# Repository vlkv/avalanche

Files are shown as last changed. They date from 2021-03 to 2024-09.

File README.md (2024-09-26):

# The Avalanche keyboard

The Avalanche keyboard is an ergonomic split keyboard with 4x6 (or 3x6 if you **break off the 'digits' row**) column staggered keys,
5 thumb keys, **1 additional key for the pinky** (break off-able too) and 2 additional keys for the index finger (64 keys total).

Avalanche design was inspired by a number of great keyboards. You may read more about it
in my very first [reddit post](https://www.reddit.com/r/MechanicalKeyboards/comments/mkwddp/introducing_the_avalanche_yet_another_one_ergo/).

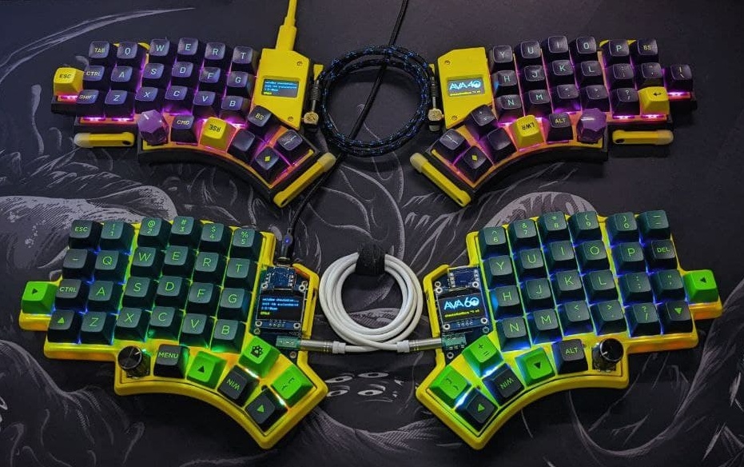
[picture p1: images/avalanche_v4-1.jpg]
The Avalanche keyboard v4

Avalanche v4 (Awesome 40% and 60% builds by [u/chewiedies](https://www.reddit.com/user/chewiedies))

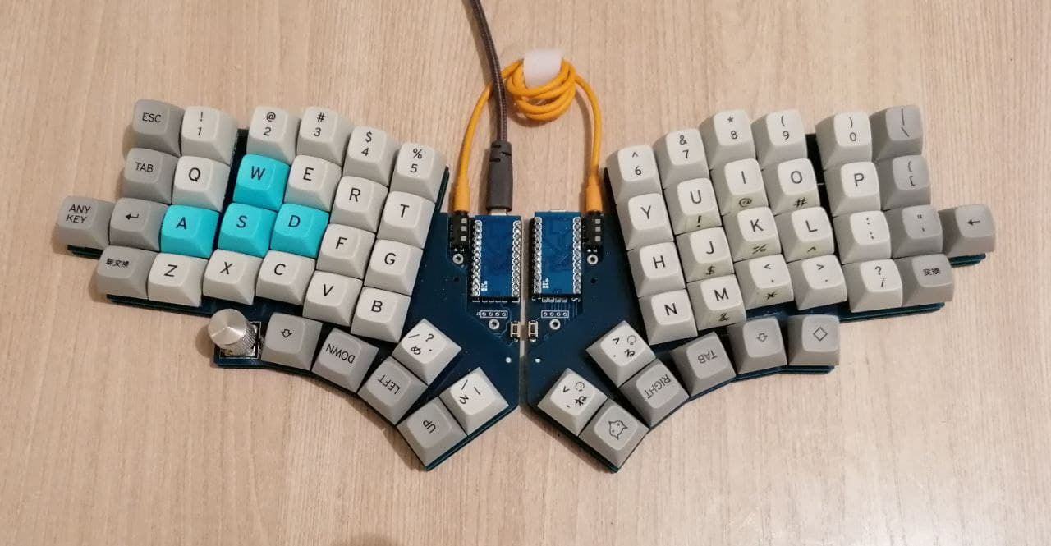
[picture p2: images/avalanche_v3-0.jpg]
The Avalanche keyboard v3

Avalanche v3

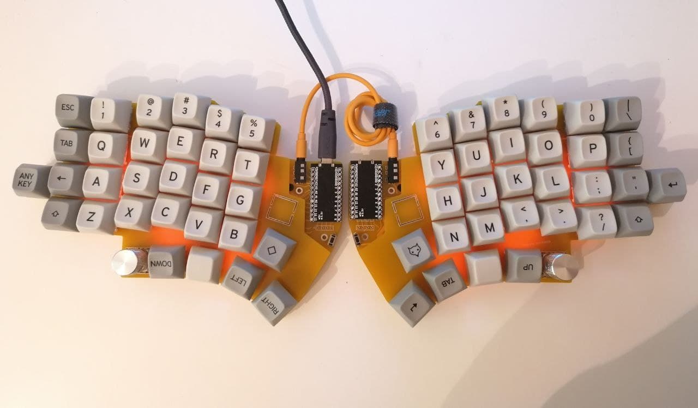
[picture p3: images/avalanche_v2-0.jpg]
The Avalanche keyboard v2

Avalanche v2

## Layout tester

Cut [left half](https://github.com/vlkv/avalanche/blob/master/layout_tester/pdf/Avalanche_v3_0_left_A4.pdf) and
[right half](https://github.com/vlkv/avalanche/blob/master/layout_tester/pdf/Avalanche_v3_0_right_A4.pdf)
from some piece of a cardboard, insert switches, put on the keycaps and try the layout.

## Gerber files

* [Version 4.2](https://github.com/vlkv/avalanche/tree/v4.2)
  * [PCB](https://github.com/vlkv/avalanche/blob/v4.2/pcb/Gerbers_pcb_v4_2.zip)
  * [Top plate](https://github.com/vlkv/avalanche/blob/v4.1/plate_top/Gerbers_plate_top_v4_1.zip)
  * [Bottom plate](https://github.com/vlkv/avalanche/blob/v4.1/plate_bottom/Gerbers_plate_bottom_v4_1.zip)
  * [60% 3D printed case](https://www.thingiverse.com/thing:5183389)
  * [40% 3D printed case](https://www.thingiverse.com/thing:5183613)
* [Version 3.1](https://github.com/vlkv/avalanche/tree/v3.1).
  * [PCB](https://github.com/vlkv/avalanche/blob/v3.1/pcb/Gerbers_pcb_v3_1.zip)
  * [Top plate](https://github.com/vlkv/avalanche/blob/v3.1/plate_top/Gerbers_plate_top_v3_0.zip)
  * [Bottom plate](https://github.com/vlkv/avalanche/blob/v3.1/plate_bottom/Gerbers_plate_bottom_v3_0.zip)
  * [Cover](https://github.com/vlkv/avalanche/blob/v3.1/cover/Gerbers_cover_v3_0.zip).
* [Version 3.0](https://github.com/vlkv/avalanche/tree/v3.0).
  * Known issues:
    * Still not fixed! https://github.com/vlkv/avalanche/issues/8
  * [PCB](https://github.com/vlkv/avalanche/blob/v3.0/pcb/Gerbers_pcb_v3_0.zip)
  * [Top plate](https://github.com/vlkv/avalanche/blob/v3.0/plate_top/Gerbers_plate_top_v3_0.zip)
  * [Bottom plate](https://github.com/vlkv/avalanche/blob/v3.0/plate_bottom/Gerbers_plate_bottom_v3_0.zip)
  * [Cover](https://github.com/vlkv/avalanche/blob/master/cover/Gerbers_cover_v3_0.zip). TODO: use git tag in this URI
* [Version 2.2](https://github.com/vlkv/avalanche/tree/v2.2).
  * Known issues:
    * Still not fixed! https://github.com/vlkv/avalanche/issues/8
  * [PCB](https://github.com/vlkv/avalanche/blob/v2.2/pcb/Gerbers_pcb.zip)
  * [Top plate](https://github.com/vlkv/avalanche/blob/v2.2/plate_top/Gerbers_plate_top.zip)
  * [Bottom plate](https://github.com/vlkv/avalanche/blob/v2.2/plate_bottom/Gerbers_plate_bottom.zip)
  * TODO: Add ProMicro/OLED cover gerber files...
* [Version 1.1](https://github.com/vlkv/avalanche/tree/v1.1).
  * [PCB](https://github.com/vlkv/avalanche/blob/v1.1/pcb/Gerbers_pcb.zip)
  * [Top plate](https://github.com/vlkv/avalanche/blob/v1.1/plate_top/Gerbers_plate_top.zip)
  * [Bottom plate](https://github.com/vlkv/avalanche/blob/v1.1/plate_bottom/Gerbers_plate_bottom.zip)

## Release notes
Are [here](https://github.com/vlkv/avalanche/blob/master/release_notes.md).

## Parts list
Is [here](https://github.com/vlkv/avalanche/blob/master/parts_list.md).

## Build instructions

Are [here](https://github.com/vlkv/avalanche/blob/master/build_instructions.md). These instructions are very brief
and insufficient as a detailed build instructions for a beginner. That is why (if you are a beginner) I recommend you
to also read these resourses:
* [ErgoTravel Build Instructions](https://github.com/jpconstantineau/ErgoTravel/blob/master/BuildInstructions.md)
* [Jian Build Instructons](https://telegra.ph/Gajd-po-sborke-Jian-12-08)
* [Joric wiki](https://github.com/joric/jorne/wiki)

## Chat group
There is a [chat group in Telegram](https://t.me/avalanche_kb), where you may chat about the project or ask some questions/help.

## Firmware

* [QMK](https://github.com/vlkv/qmk_firmware/tree/master/keyboards/avalanche).
* [ZMK from our friend romones](https://github.com/romones/zmk-config). According to him: "Keyboard works, encoders work. I couldn’t figure out lights and displays. And if you plan to use it note there is an override for a dead pin in right overlay".

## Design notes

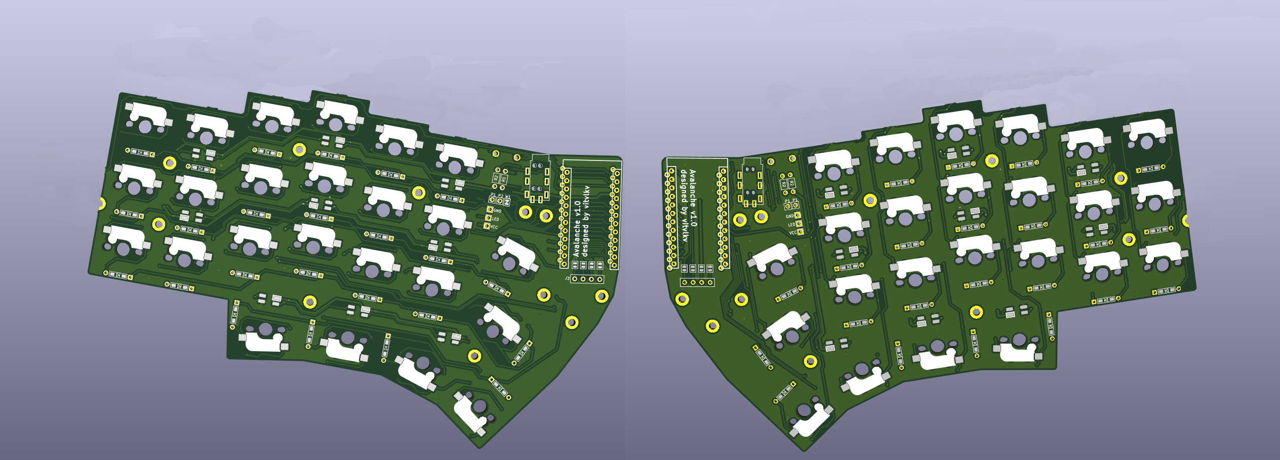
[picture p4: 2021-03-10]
images/avalanche48_PCBs_3d_model.png

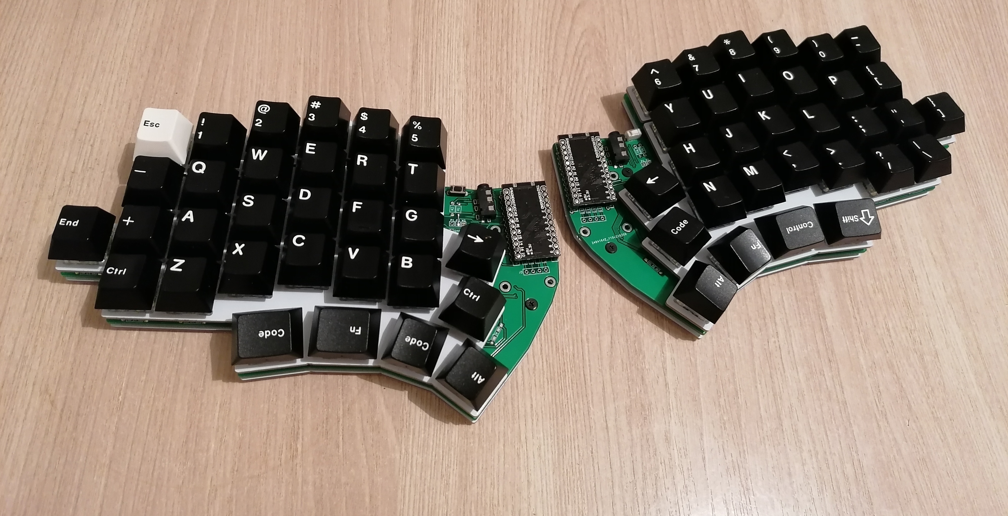
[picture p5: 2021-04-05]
images/avalanche_v1-0.jpg

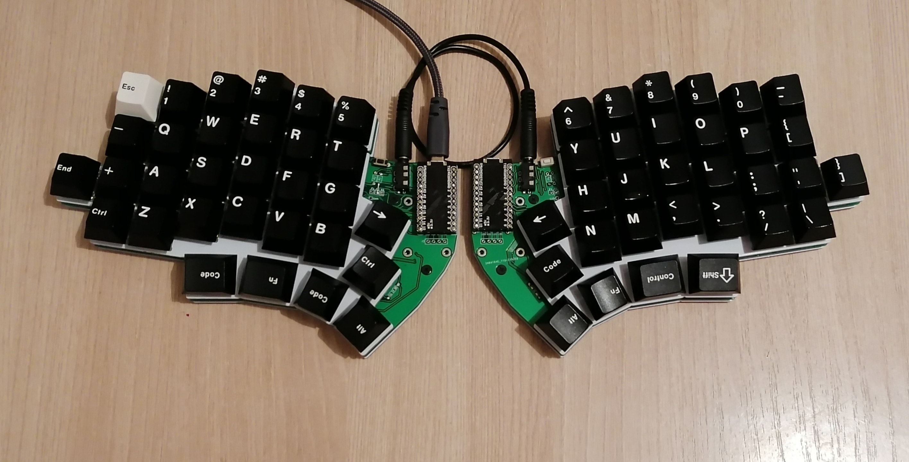
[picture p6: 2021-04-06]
images/avalanche_v1-0_01.jpg

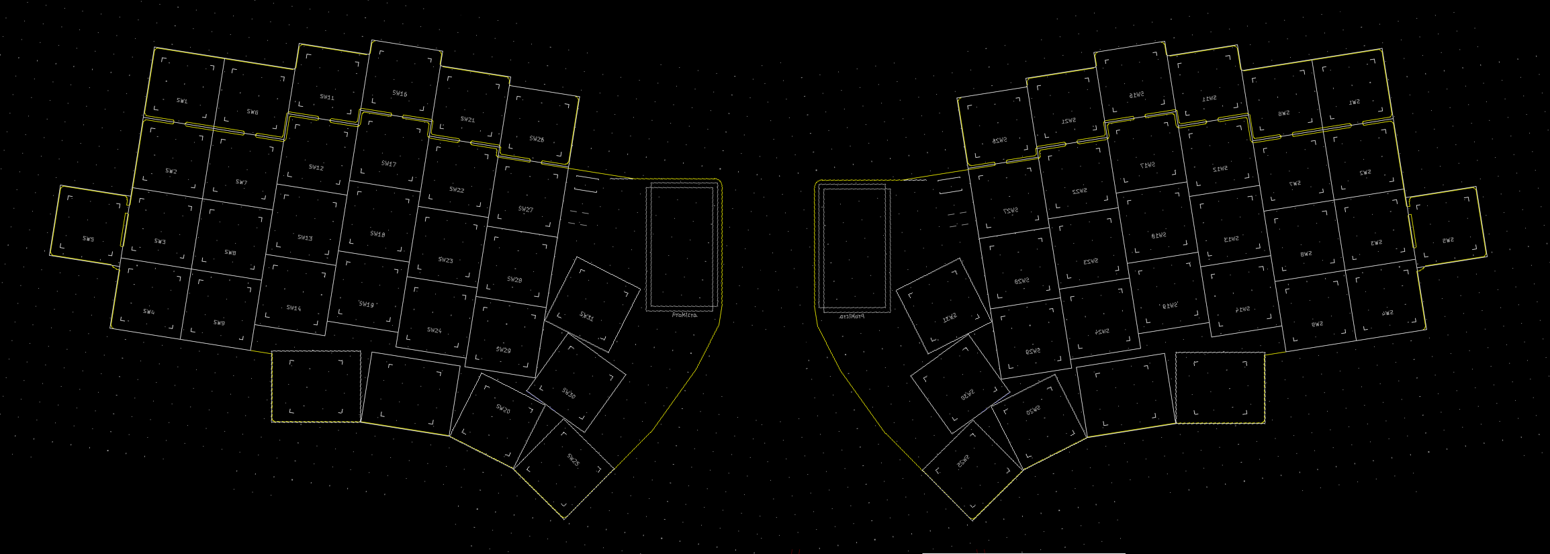
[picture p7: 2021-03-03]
images/avalanche_mockup_03.png

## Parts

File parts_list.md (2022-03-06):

## Parts list

| #  | Name | Quantity | Example URL |
|----|---|---|---|
| 1  | PCB | 2 | |
| 2  | Top plate | 2 | |
| 3  | Bottom plate | 2 | |
| 4  | ProMicro (ATmega32U4 5V/16MHz) | 2 | https://aliexpress.ru/item/2010847161.html |
| 5  | Sockets for ProMicro 3.5mm | 2 | https://aliexpress.ru/item/32360715483.html |
| 6  | Kailh hotswap sockets | 64 | https://aliexpress.ru/item/32903471019.html |
| 7  | Diode 1N4148 (SMD or through hole) | 64 | https://aliexpress.ru/item/32881432301.html |
| 8  | TRRS sockets PJ320A | 2 | https://aliexpress.ru/item/32368285821.html |
| 9  | TRRS Cable (straight connectors) | 1 | https://aliexpress.ru/item/32462922130.html |
| 10 | Reset button (DIP switch) | 2 | https://aliexpress.ru/item/4000209910403.html |
| 11 | Bumpons for bottom plate (set) | 1 | https://aliexpress.ru/item/32912066603.html or https://aliexpress.ru/item/32680543746.html |
| 12 | M2 screws 3mm | 18 | https://aliexpress.ru/item/32976056190.html |
| 13 | M2 standoffs 7mm | 18 | https://aliexpress.ru/item/32597776358.html |
| 14 | Rotary encoder | 2 | https://aliexpress.ru/item/32976046900.html |
| 15 | Knob (for rotary encoders) | 2 | https://www.aliexpress.com/item/33004945608.html |
| 16 | Keyboard switch (Cherry-MX compatible) | 64 | |
| 17 | Keycaps set (Cherry-MX compatible) | 1 | |

NOTE: Rotary encoders and knobs are optional. But I recommend them. That is why they are in the main list.

Optional LED. Choose either backlight or per-switch (not both)

| #  | Name | Quantity | Example URL |
|----|---|---|---|
| 18 | LED (backlight) WS2812B (for v1..v3) | 12 | https://aliexpress.ru/item/32774508291.html |
| 19 | LED (per switch) SK6812 MINI-E | 64 | https://aliexpress.ru/item/4000475685852.html |

Optional for I2C connection (instead of serial)

| #  | Name | Quantity | Example URL |
|----|---|---|---|
| 20 | Resistor 4.7K (through hole or SMD)  | 2 | https://aliexpress.ru/item/32882582185.html |

Optional OLED Screen

| #  | Name | Quantity | Example URL |
|----|---|---|---|
| 21 | OLED screen (for v1..v3) | 2 | https://aliexpress.ru/item/32798439084.html |
| 22 | OLED screen (for v4) | 2 | https://aliexpress.ru/item/32896971385.html |

Optional power toggle switches. SW33 for battery, SW34 for OLED Screen and LEDs.

| #  | Name | Quantity | Example URL |
|----|---|---|---|
| 23 | Side access toggle switch | 2-4 | https://aliexpress.ru/item/4001295557976.html |

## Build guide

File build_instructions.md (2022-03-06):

## The Avalanche keyboard build instuctions

### Break off the numbers row and pinky key

If desired, break off the number row and/or pinky key

### Diodes

Both SMD and through-hole types of diodes are supported. The stripe on the diode should match the silk screen so that the line on the diode is on the same side.

Through-hole diodes are nice when using Mill-Max sockets because the trimmed diode wires can be used as the ProMicro pins.

### Switch hotswap sockets

Install the hotswap sockets on the same side as the diodes.

I recommend the following way of soldering the hotswap sockets. Take the top plate, insert all switches into the top plate holes. Then place the top plate onto the PCB. Take switch sockets and place them to their dedicated places on the bottom side of the PCB. The switch sockets will be fixed with the switch pins stopping them from falling away or move anywhere around. Now solder the switch sockets to the PCB (with comfort).

### Component locations

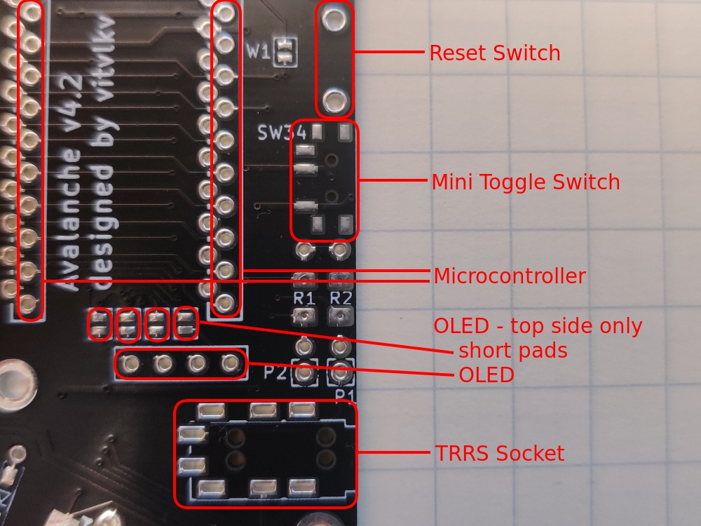
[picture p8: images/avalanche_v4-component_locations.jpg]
v4 Component locations


### ProMicro sockets

Mill-Max headers must be used, standard header pins do not fit.

Install the ProMicro on the opposite side as the sockets and diodes. Install the ProMicro upside down for a cleaner look, the silk screen indicates where the headers should be seated. To install the ProMicro right side up, use the other header position.

Solder the sockets to the PCBs. Solder one pin, adjust by resoldering the one pin until socket is positioned at 90 degrees. Only after that solder other pins. Be careful when soldering the socket's pins to avoid bridging the unused pads. You should not short circuit unused pads with the pins.

For low profile Mill-Max type headers, you can now solder the ProMicro header pins. This is a good time to re-use the diode legs if through-hole diodes were used. Solid core 24 AWG wire also works very well. Put some painter's tape (or similar) between sockets and ProMicros before soldering the pins, otherwise solder could leak into the sockets.

### Reset switch, TRRS socket, toggle switches.

Solder them on the same side as the ProMicro.

SW33 toggle switch (not pictured) can be used in wireless builds to disconnect the battery.

SW34 toggle switch controls power to the OLED Screen and LEDs, which is useful for wireless builds. For wired builds the switch can be replaced, and permenantly enabled, by connecting the SW34 pads with a wire.

### OLED

Install headers below the ProMicro sockets and bridge the nearby pads on the same side as the OLED. If the ProMicro has already been installed you may need to remove it in order to access the pads.

### Choose Serial or I2C
I2C provides less latency in communication between the halves of the keyboard. This latency difference begins to be noticible when typing above 100 words per minute.

* I2C: On the master board (left by default) solder 4.7k resistors R1, R2.
  On the secondary board (right by default) connect P1 to R1 and P2 to R2 (the closest holes to each).
  Modify your qmk firmware `config.h` with `#define USE_I2C` instead of `#define USE_SERIAL`.
  Use only TRRS cable to connect keyboard halves.

* Serial: On both halves you should short circuit the W1 jumper.
  Modify your qmk firmware `config.h` with `#define USE_SERIAL` instead of `#define USE_I2C`.
  Use TRS or TRRS cable to connect keyboard halves.

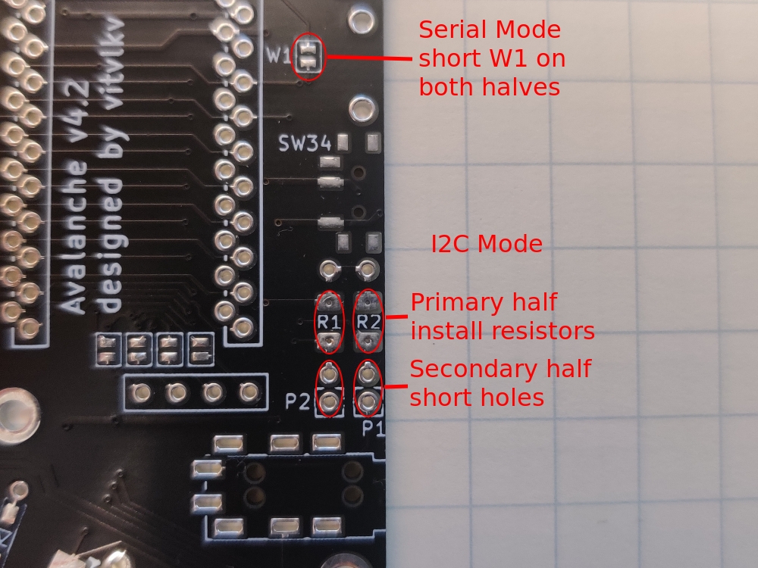
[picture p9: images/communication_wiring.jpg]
Communication wiring


This doc of the [QMK site](https://beta.docs.qmk.fm/using-qmk/hardware-features/feature_split_keyboard) has
additional information.

### LEDs

Install LEDs on the same side of the PCB as the hotswap sockets. The ground pin on the LED is indicated with a notched lead, line this up with the angle mark on the PCB. This component can be damaged if it gets too hot, so be careful not to dwell with the soldering iron for more than 2-3 seconds, and keep the temperature low.

One way to approach this component is to put a blob of solder on each ground pad first. With tweezers carefully hold the LED in position above the blob and quickly attach it to the blob. Once attached, used the tweezers to gently push down on the LED to fully seat it to the PCB. Inspect the alignment and carefully adjust as needed. Once in the correct location, the remaining pins can be soldered. It is easy to bridge the legs so closely inspect your work with a loupe or multimeter.

* Short circuit the J9, J10, J11 jumpers if you are not using the number row.

#### v3 and earlier

* Backlight LEDs available in earlier revisions. Solder them in. This component is much more difficult than the other type of LED, though a similar approach can be taken. Good luck.

* For per-switch LEDs, short circuit the data-in of the first backlight LED with the data-in of the first per-key LED using a wire (or data-in to data-out pins on all backlight LEDs). Of course, it is supposed that you do not install the backlight LEDs at all.

### Rotary encoders
* IMPORTANT NOTE: Only 1 rotary encoder could be installed on each half.
* Solder all 7 pins of rotary encoders to the PCB this fixes the encoder the best.
* Do not install both kailh socket and rotary encoder into the same switch slot on the PCB. Install either one.

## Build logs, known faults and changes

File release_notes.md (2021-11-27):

## Release notes

### v4
* Compacted and redesigned stuff around ProMicro.
* Column stagger was made less agressive.
* Less angle for the "pinky stagger" of the 5th and 6th colums.
* Changed OLED to horizontal one (SSD1306 128x64).
* Removed support for the background lighting (so, there is only per-switch lighting on board).
* Since v4.1: Changed the edge cuts of the PCB a little bit, so after breaking the numbers row the PCB is
  more neat and pretty. ATTENTION: this required changing the position of the three top mounting holes, so
  the top/bottom plates of **v4.0 and v4.1 are not compatible**.

### v3

* Changed the thumb cluster (see the image).
* Since v3.1: Fixed issue with per-switch LEDs facing down. Now, they facing up.

### v2.1

* Fixed issue with R1 resistor.

### v2.0

* Moved (a bit) thumb cluster to the center making the fourth thumb button more comfortable.
* Added the fifth button to the thumb cluster (mostly for rotary encoders).
* Added rotary encoders support.
* Rotated (a bit) three outer columns for better pinky reach.
* Changed the shape of top and bottom plates (as well as the PCBs).
* Added support for per-switch RGB lighting.
* Changed footprints for backlight RGB lighting.
* Changed footprints for switch sockets to a different ones.
* Moved reset button.
* Moved mounting holes.
* Other minor fixes...

Issues:
* Resistor R1 is turned upside down, making it harder to enable I2C.

### v1.1

The issue with TRRS socket has been fixed. So this version should be OK to build.

### v1.0

This is the very first prototype version. It had major issue: TRRS socket had a wrong position. It is not fatal,
you can fix it with some cutting with a file. It is not recommend to build this version.

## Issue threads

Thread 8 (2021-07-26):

Per-key LED footprint is incorrect

vlkv, 2021-07-26:
The per-key LEDs are facing down now. They should be mounted facing up. This bug is in the Avalanche v2 and v3.

Closed 2021-12-10.

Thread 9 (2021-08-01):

Problems after breaking-off the numbers row

vlkv, 2021-08-01:
Thanks to Brent Stromberg, [he discovered](https://t.me/avalanche_kb/993) that on a 40% avalanche (after you break off the numbers row):
```
However the encoder twists do not register.
They send KC on press, but no knob turns.
Also the reset button does not work
```

And the problem is in the PCB, see image: https://imgur.com/a/KO09Qfu

P.S. Workaround - connect with a wire GND to the reset button (see pink trace drawing on the image above).

Closed 2021-11-27.

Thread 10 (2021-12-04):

GND shortened to RST in Avalanche 4.0 and 4.1

vlkv, 2021-12-04:
Also there is a problem with tracks on the 'F' key: VCC track shortens to one of the diode pad.

Closed 2021-12-10.

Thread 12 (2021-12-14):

Differences between v3 and v4

DLopezGo90, 2021-12-14:
The only differences are the microcontroller and OLED position? the layout for keys has not been changed?

Thanks in advance

vlkv, 2021-12-14:
Hi))) https://github.com/vlkv/avalanche/blob/master/release_notes.md#v4

DLopezGo90, 2021-12-14:
No more RGB underglow support? (backlight)

Not even LEDs strip?

vlkv, 2022-02-24:
> Not even LEDs strip?
Well, at least not yet. Pads for LEDs strip could be added I guess, have no word against this idea)

DLopezGo90, 2022-03-06:
> Well, at least not yet. Pads for LEDs strip could be added I guess, have no word against this idea)

I think it was a mistake to remove the underglow leds. Avalanche competitors (corne, sofle rgb, kyria, etc) have underglow leds. If FR4 or acrylic plates are used to build an avalanche the lack of underglow leds will be evident

Closed 2022-03-18.

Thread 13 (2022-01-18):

v4.2 JLCPCB Order

winder, 2022-01-18:
I'm ordering some v4.2 PCBs and JLCPCB sent the following question. From the image it looks like the holes are green, does this mean the hotswap sockets and spring housing hole are missing?
```
As shown below, it seems this is a working gerber ready for production, is that right?

Shall we fabricate as per this gerber without further compensation and optimization?
```

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

vlkv, 2022-01-18:
`As shown below, it seems this is a working gerber ready for production, is that right?`
Yes
`Shall we fabricate as per this gerber without further compensation and optimization?`
Ask them, what do they mean by `compensation and optimization`?

` From the image it looks like the holes are green, does this mean the hotswap sockets and spring housing hole are missing?`
Have no idea what that could mean.

winder, 2022-01-18:
This looks relevant to the missing through holes:
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

vlkv, 2022-01-19:
Hi! I really do not know. Their previewer is not perfect, that is for sure. Anyway, if you have doubts then I recommend you to ask jlcpcb engineers/support about that. Tell them that you need those LED holes, and that previewer doesn't show them.

winder, 2022-01-19:
I'll talk with support to address these items. Thanks for the help, your comments were more encouraging than you may realize!

winder, 2022-02-15:
Received the shipment today. Everything seems to be in order. Thanks so much for the help, and for open sourcing your design.

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

Closed 2022-02-15.

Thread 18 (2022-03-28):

Is 4.2 released? or is the README up to date that still recommends to wait?

maxhbr, 2022-03-28:

vlkv, 2022-03-29:
Hi, v4.2 version is OKay, several people already built it, without any issues (as far as I know). Gerbers are here https://github.com/vlkv/avalanche#gerber-files

Can you please show me, where the README recommends to wait? This could be an outdated info, that should be corrected.

maxhbr, 2022-03-29:
I am very sorry. I accidentally was on https://github.com/vlkv/avalanche/tree/v4.2, where the README is not yet updated. It is all OK on master

vlkv, 2022-03-29:
No problem, I am glad that everything is good)

Closed 2022-03-29.

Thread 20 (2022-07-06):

[v4.2] Shorting the SW34 pads for the OLED causes a short on the Pro Micro

cam443, 2022-07-06:
I'm not sure if I'm doing something incorrectly, but when I bridge the SW34 pads to try to enable the OLED, my pro micro doesn't start. Desoldering the bridge fixes the issue. I have LEDS installed if that would affect anything.

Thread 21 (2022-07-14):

60% 3D printed case link issue

waboni1, 2022-07-14:
Hi, just wanted to know if you may re-upload the thing file at thingiverse, seems that it is down.

ashleysommer, 2022-10-05:
Its pretty easy to find by searching thingiverse, for [uploads by the same contributor](https://www.thingiverse.com/chewiedies/designs).
The correct [link](https://www.thingiverse.com/thing:5395703) is this:
https://www.thingiverse.com/thing:5395703

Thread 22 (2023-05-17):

Split Communication Issues

m-reiner, 2023-05-17:
I've been struggling for around a week trying to get either serial or i2c working between the halves.

To try and get i2c working, I've added through hole resisters to the left side using the holes above the SMD pads for R1 and R2, and jumpers between the P1/2 holes and the bottom through holes for R1/2. I tried adding #define USE_I2C in both the v4 config.h as well as my keymap's config.h, but I could never get it to work.

I gave up on i2c and tried to at least get serial working by bridging the W1 pad on both sides' PCBs and then adding #define USE_SERIAL in both the v4 config.h as well as my keymap's config.h, but I could never get it to work.

I've built 4x PCBs, swapped out microcontrollers, verified continuity between the TRRS jacks with a multimeter, and tried a different TRRS cable (both cables worked fine with my dactyl manuform). No matter what I tried, I can't seem to get it to work.

The only thing that kind of worked was setting #define EE_HANDS and flashing each half as specifically the right or left side. If I then hook USB cables from each side's microcontroller to my computer (without a TRRS cable, of course), it kinda works though it's super laggy.

I tried not to bother you, but I've been stuck for around a week at this point and I REALLY like the V4's design. Anything you can suggest to help me get this working, preferably using i2c, would be sincerely appreciated.

kenzya, 2023-08-07:
I built an avalanche v4 today and I have this exact issue. i2c or serial aren't working. I tried using the .hex files provided by beekeeb here: https://docs.beekeeb.com/build-guide/avalanche-v4.2-photo-build-log and have the exact same issue. Hooking each half up individually, key presses and screen work no problem. I also hooked both halves up each with a usb-c at the same time, both screens powered on, and then I pulled the usb-c from the right side, and the screen stayed on so it must be getting power from the TRRS connector. But just plugging in the left side, no key presses work on the right side and the screen won't power on.

I've soldered on the resistors to the left half, bridged the two points on the right half, set use_i2c in the config, compiled and flashed to both halves. 2nd half doesn't work. I removed the resistors, unbridged the two pads, bridged w1 on both halves, set use_serial in the config, compiled and flashed to both halves. 2nd half doesn't work.

vlkv, 2023-08-07:
Hello,
I would love to help, but I am using Chocofly keyboard for more than a year and forget most of the details about how to get up and running the Avalanche with i2c/serial. The only info resourse is https://github.com/vlkv/avalanche/blob/master/build_instructions.md#choose-serial-or-i2c (and it worked as I remember) and our community chat: https://t.me/avalanche_kb
The best advice here is to ask help from some people in that community chat. There are a lot of people who will gladly help you.

Thanks.

misel228, 2024-10-20:
Hello,

I'm late to the party but I faced similar problem. No matter what I tried, I couldn't get I2C communication working.

But then I came across [this post on Reddit](https://www.reddit.com/r/olkb/comments/10dilzl/comment/jl5dh3p/)

There, compfixer87 posted that he got it working by shorting P1 and P2 on the **primary** half. The image in the build instructions (https://github.com/vlkv/avalanche/raw/master/images/communication_wiring.jpg) mentions the secondary half but that seems to be wrong.

This helped me getting it running with I2C and I hope it can help you or others, too.

m-reiner, 2024-10-21:
Thanks so much for sharing!

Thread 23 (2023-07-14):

v4.2 compatible QMK firmware

filoxo, 2023-07-14:
Following up on https://github.com/vlkv/avalanche/issues/19. Have you released a v4.2 compatible QMK fork, or any info on where to find/obtain that? The [QMK repo linked to in the readme](https://github.com/vlkv/qmk_firmware/tree/master/keyboards/avalanche) only has v3. I had hoped the firmware wouldn't require many changes but flashing v3 onto a v4.2 pcb doesn't seem to work at all (OLEDs are garbled, no LEDs, no keystrokes worked). I found a [functional .hex file by beekeeb](https://docs.beekeeb.com/build-guide/avalanche-v4.2-photo-build-log) which does work, so someone somewhere has it working. Any help or pointers would be appreciated, thank you!

filoxo, 2023-07-14:
Well... I feel silly. v4 support was merged into the main QMK repo, available here: https://github.com/qmk/qmk_firmware/tree/master/keyboards/avalanche/v4

Closed 2023-07-14.

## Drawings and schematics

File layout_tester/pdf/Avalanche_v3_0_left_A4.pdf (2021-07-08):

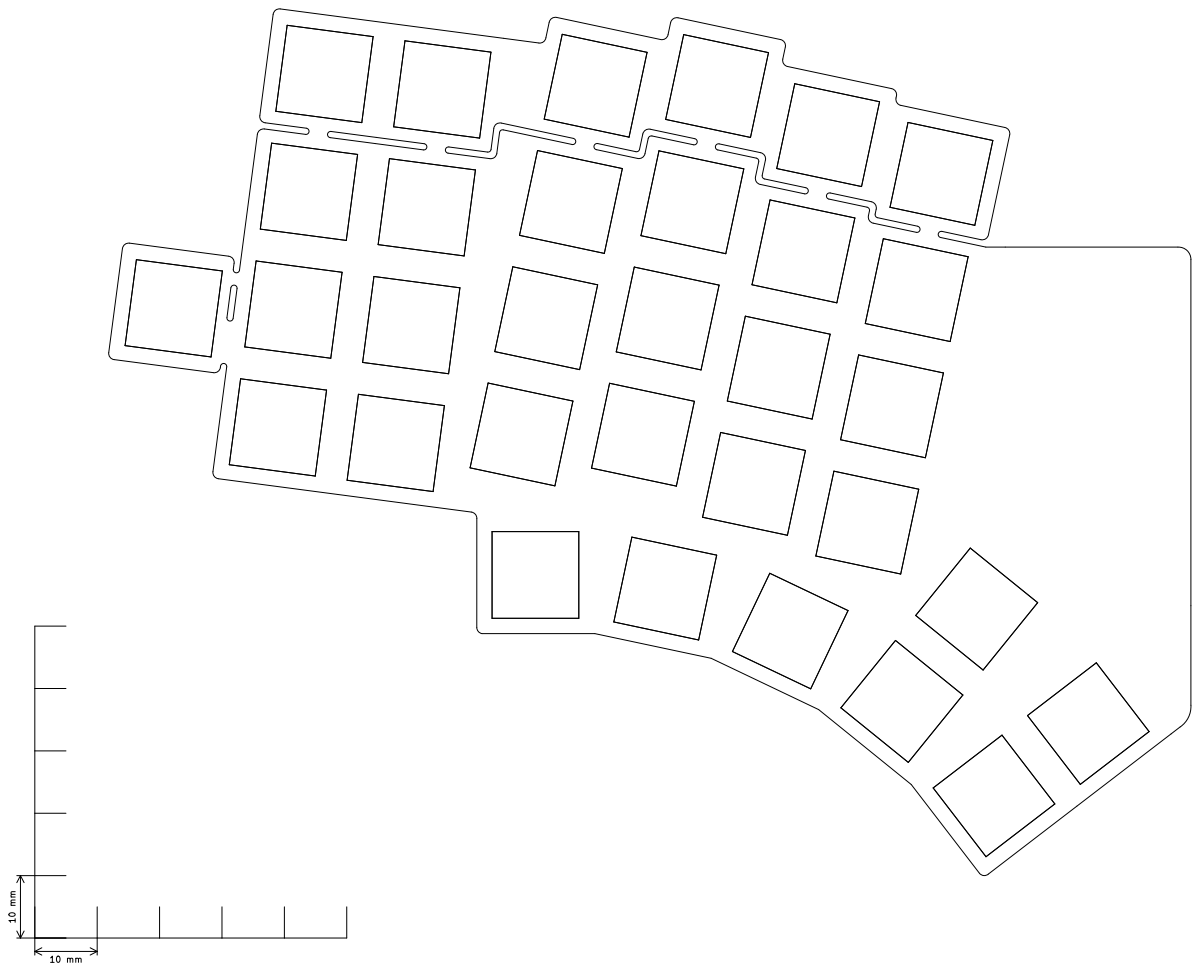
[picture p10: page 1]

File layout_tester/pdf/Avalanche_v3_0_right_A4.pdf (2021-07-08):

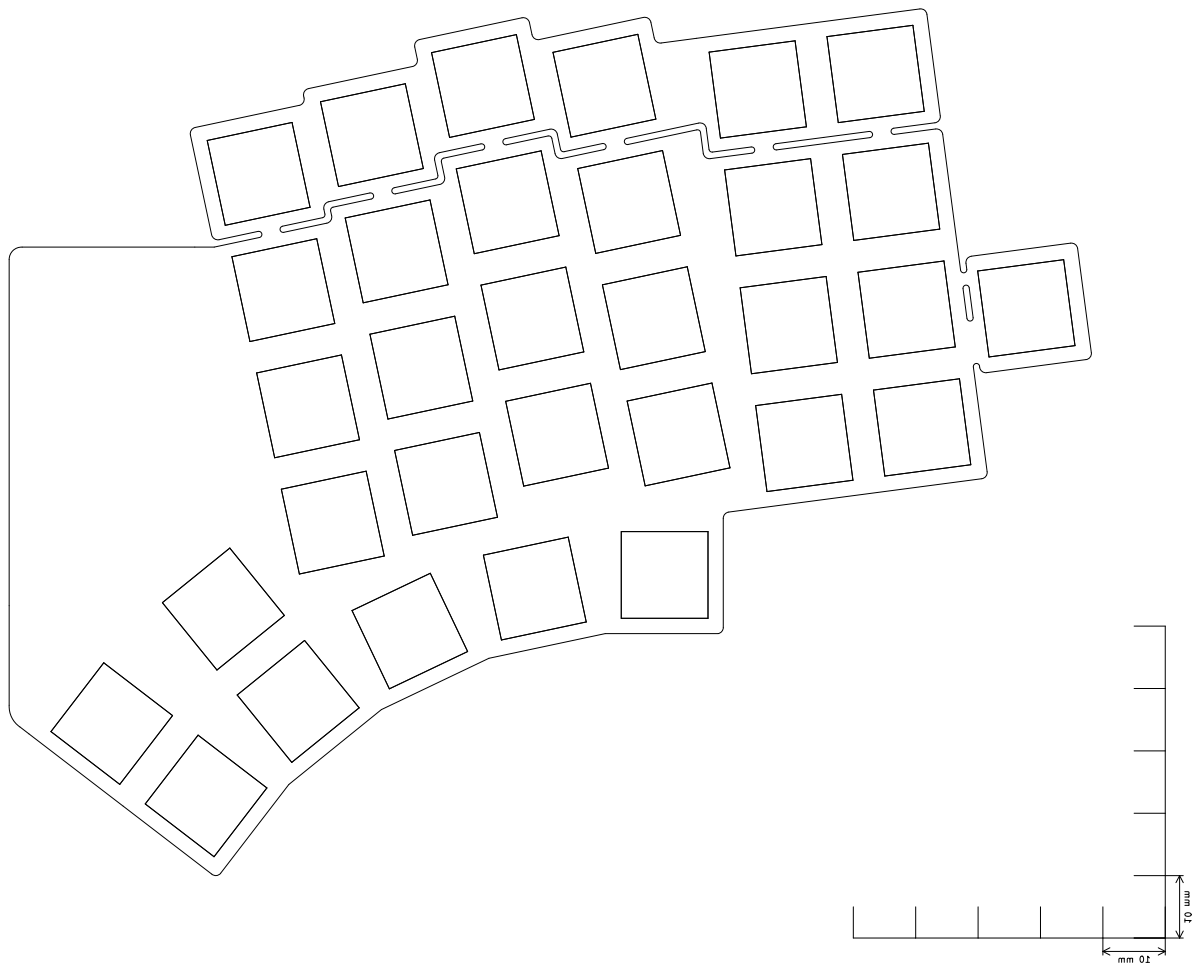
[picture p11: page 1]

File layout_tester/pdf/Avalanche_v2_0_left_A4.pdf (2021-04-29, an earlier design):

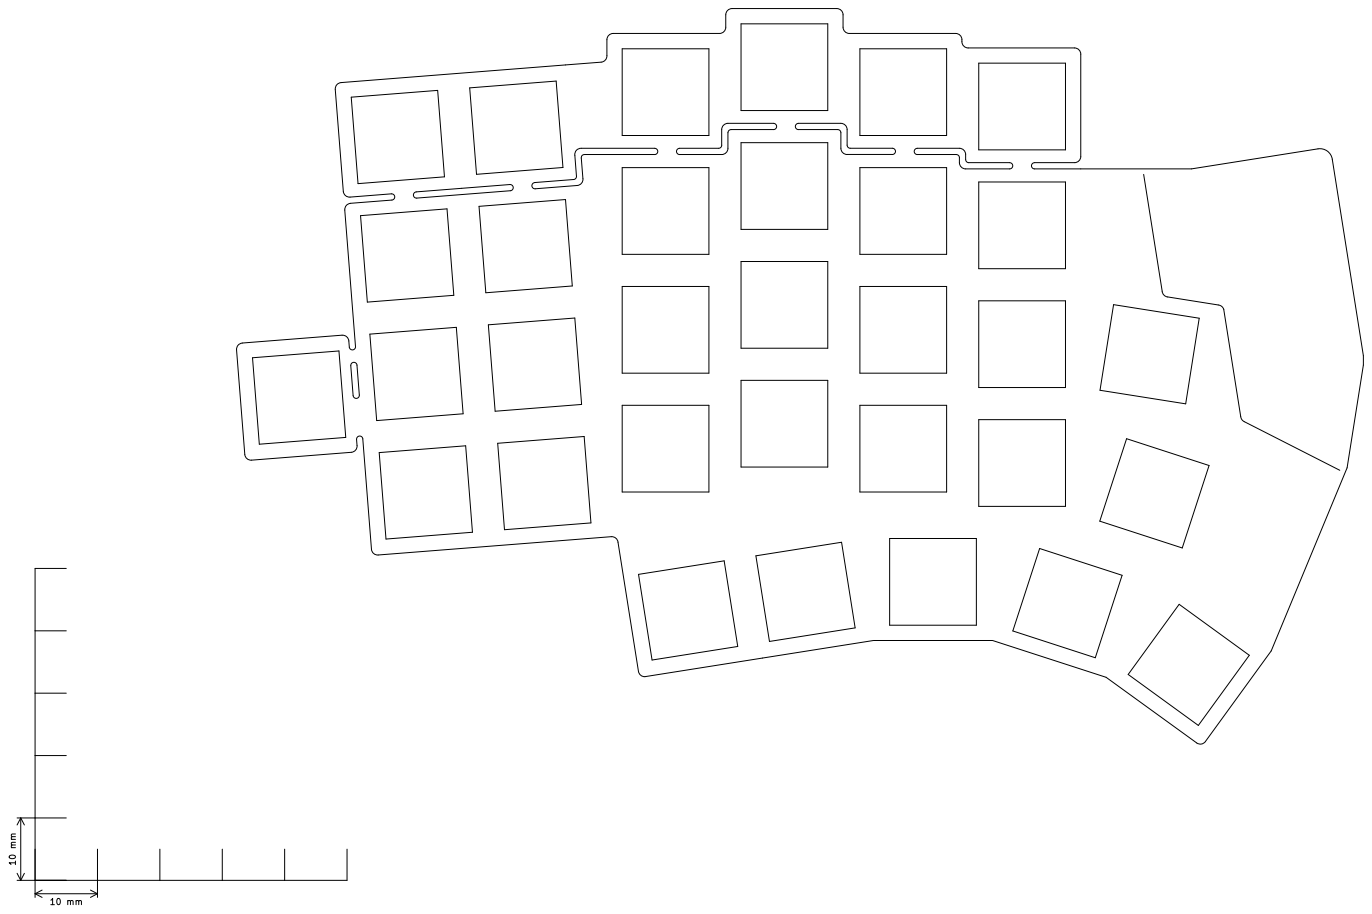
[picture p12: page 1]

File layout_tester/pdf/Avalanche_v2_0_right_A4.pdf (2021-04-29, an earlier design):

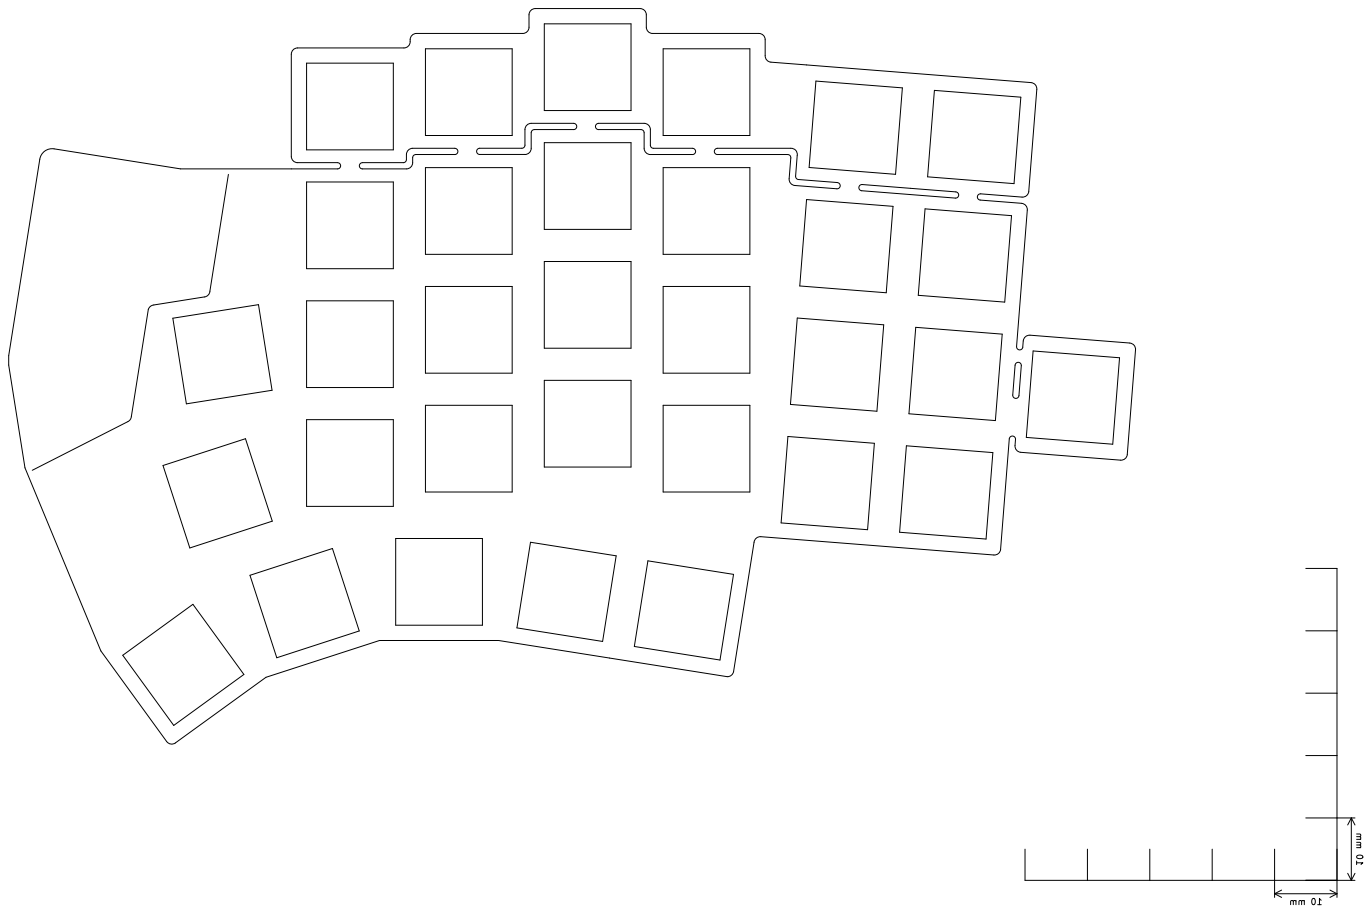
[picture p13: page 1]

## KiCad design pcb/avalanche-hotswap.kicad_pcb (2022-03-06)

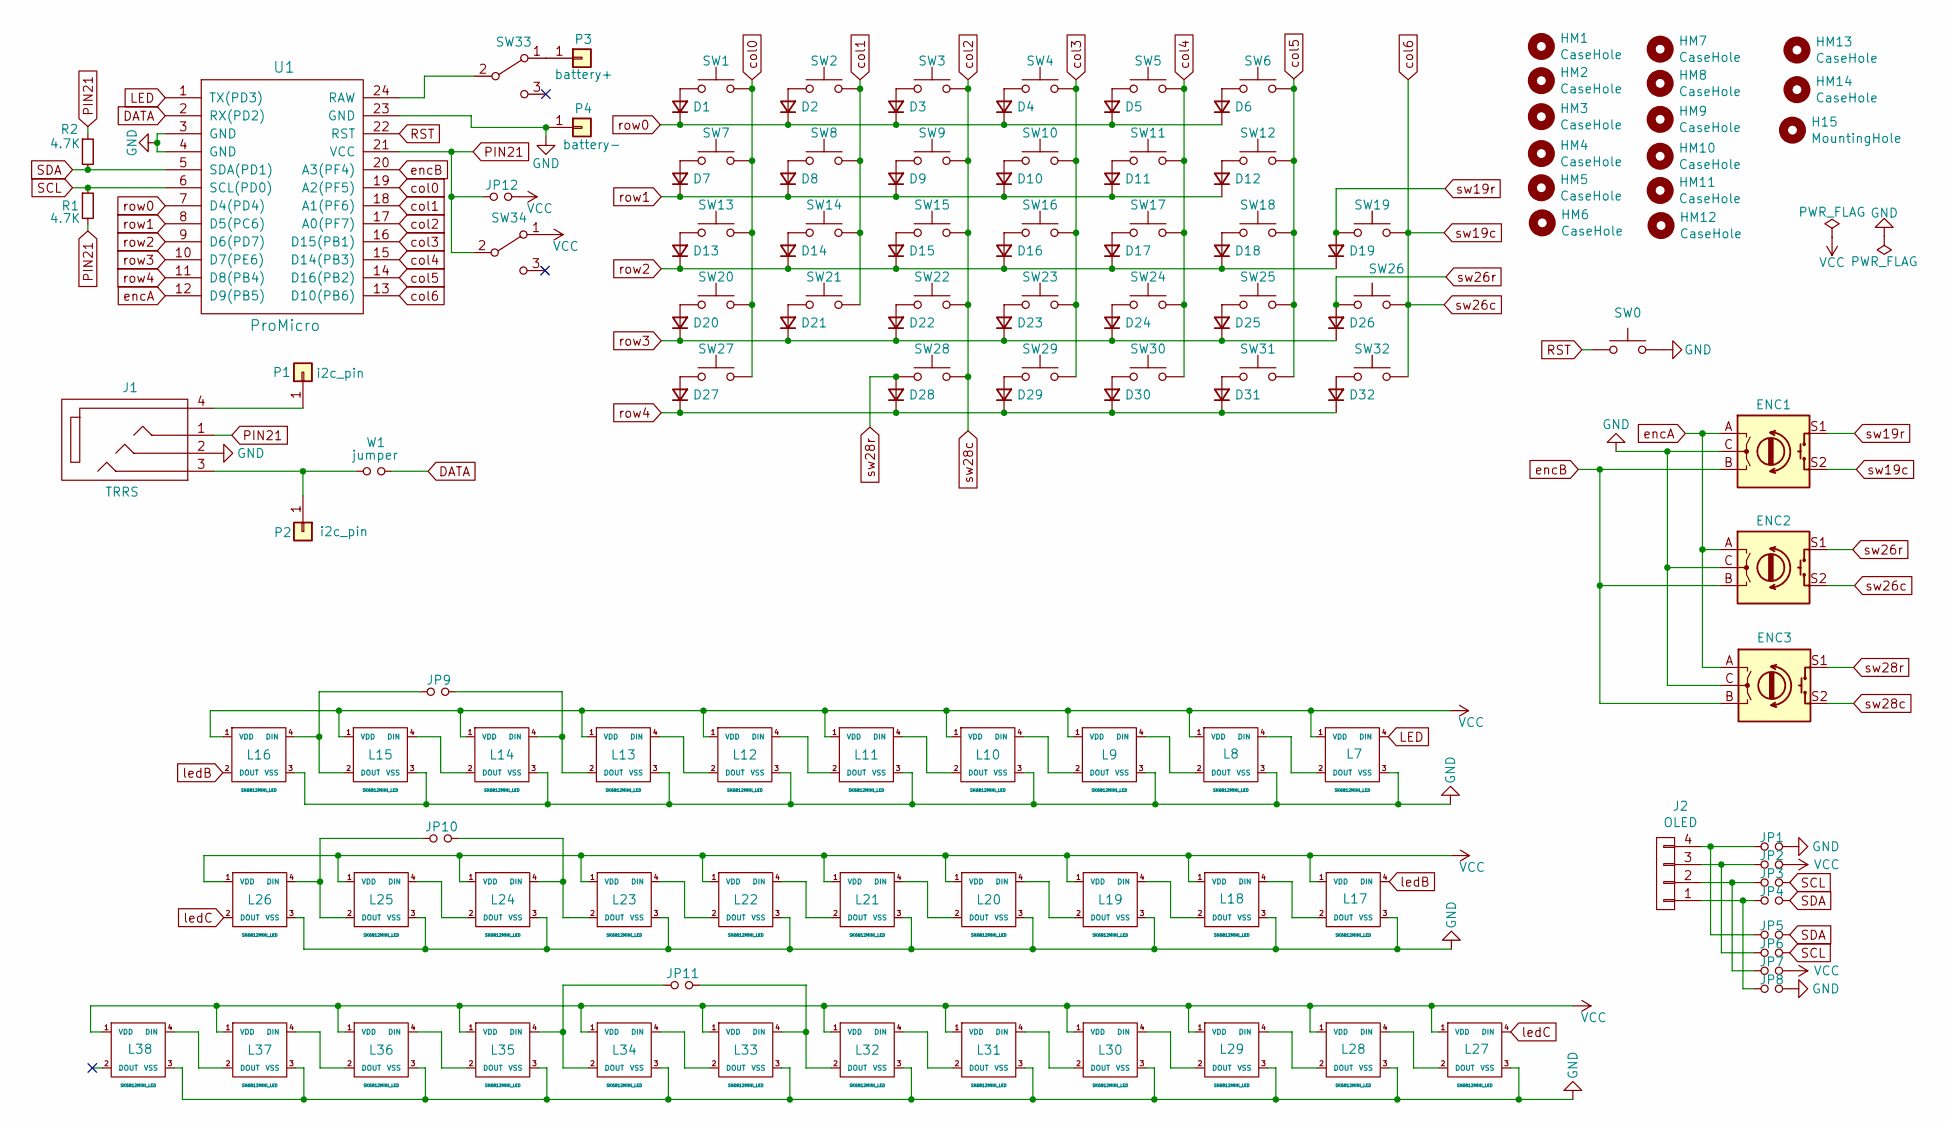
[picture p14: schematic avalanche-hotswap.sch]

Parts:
D1, D2, D3, D4, D5, D6, D7, D8, D9, D10, D11, D12, D13, D14, D15, D16, D17, D18, D19, D20, D21, D22, D23, D24, D25, D26, D27, D28, D29, D30, D31, D32: 1N4148; diode_TH_SMD
ENC1, ENC2, ENC3: Rotary_Encoder_Switch; RotaryEncoder_Alps_EC11E-Switch_Vertical_H20mm-keebio_modif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
H15: MountingHole; M2_HOLE_PCB
HM1, HM2, HM3, HM4, HM5, HM6, HM7, HM8, HM9, HM10, HM11, HM12, HM13, HM14: CaseHole; M2_HOLE_PCB
J1: TRRS; MJ-4PP-9
J2: OLED; OLED_4Pin_SSD1306
JP1, JP2, JP3, JP4, JP5, JP6, JP7, JP8, JP12: Device_Jumper_NO_Small; avalanche_Jumper
JP9, JP10, JP11: Device_Jumper_NO_Small; Jumper_rev
L7, L8, L9, L10, L11, L12, L13, L14, L15, L16, L17, L18, L19, L20, L21, L22, L23, L24, L25, L26, L27, L28, L29, L30, L31, L32, L33, L34, L35, L36, L37, L38: SK6812MINI_LED; YS-SK6812MINI-E
P1, P2: i2c_pin; 1pin_conn
P3: battery+; 1pin_conn
P4: battery-; 1pin_conn
R1, R2: 4.7K; Resistor_Hybrid_1205
SW0: SW_Push; Switch_Reset_THT
SW1, SW2, SW3, SW4, SW5, SW6, SW7, SW8, SW9, SW10, SW11, SW12, SW13, SW14, SW15, SW16, SW17, SW18, SW19, SW20, SW21, SW22, SW23, SW24, SW25, SW26, SW27, SW28, SW29, SW30, SW31, SW32: SW_Push; CherryMX_MidHeight_Hotswap_1u
SW33, SW34: SW_DPDT_x2; Switch_MSK-12C01-07
U1: ProMicro; ProMicro_rev2
W1: jumper; avalanche_Jumper

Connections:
DATA: U1.2 (RX(PD2)), W1.1
GND: ENC1.C, ENC2.C, ENC3.C, J1.2, JP1.2, JP8.2, L7.3 (VSS), L8.3 (VSS), L9.3 (VSS), L10.3 (VSS), L11.3 (VSS), L12.3 (VSS), L13.3 (VSS), L14.3 (VSS), L15.3 (VSS), L16.3 (VSS), L17.3 (VSS), L18.3 (VSS), L19.3 (VSS), L20.3 (VSS), L21.3 (VSS), L22.3 (VSS), L23.3 (VSS), L24.3 (VSS), L25.3 (VSS), L26.3 (VSS), L27.3 (VSS), L28.3 (VSS), L29.3 (VSS), L30.3 (VSS), L31.3 (VSS), L32.3 (VSS), L33.3 (VSS), L34.3 (VSS), L35.3 (VSS), L36.3 (VSS), L37.3 (VSS), L38.3 (VSS), P4.1, SW0.2, U1.3 (GND), U1.4 (GND), U1.23 (GND)
LED: L7.4 (DIN), U1.1 (TX(PD3))
unnamed: D1.2 (A), SW1.1
unnamed: D2.2 (A), SW2.1
unnamed: D3.2 (A), SW3.1
unnamed: D4.2 (A), SW4.1
unnamed: D5.2 (A), SW5.1
unnamed: D6.2 (A), SW6.1
unnamed: D7.2 (A), SW7.1
unnamed: D8.2 (A), SW8.1
unnamed: D9.2 (A), SW9.1
unnamed: D10.2 (A), SW10.1
unnamed: D11.2 (A), SW11.1
unnamed: D12.2 (A), SW12.1
unnamed: D13.2 (A), SW13.1
unnamed: D14.2 (A), SW14.1
unnamed: D15.2 (A), SW15.1
unnamed: D16.2 (A), SW16.1
unnamed: D17.2 (A), SW17.1
unnamed: D18.2 (A), SW18.1
unnamed: D20.2 (A), SW20.1
unnamed: D21.2 (A), SW21.1
unnamed: D22.2 (A), SW22.1
unnamed: D23.2 (A), SW23.1
unnamed: D24.2 (A), SW24.1
unnamed: D25.2 (A), SW25.1
unnamed: D27.2 (A), SW27.1
unnamed: D29.2 (A), SW29.1
unnamed: D30.2 (A), SW30.1
unnamed: D31.2 (A), SW31.1
unnamed: D32.2 (A), SW32.1
unnamed: J1.3, P2.1, W1.2
unnamed: J1.4, P1.1
unnamed: J2.1, JP4.1, JP8.1
unnamed: J2.2, JP3.1, JP7.1
unnamed: J2.3, JP2.1, JP6.1
unnamed: J2.4, JP1.1, JP5.1
unnamed: JP9.1, L15.2 (DOUT), L16.4 (DIN)
unnamed: JP9.2, L13.2 (DOUT), L14.4 (DIN)
unnamed: JP10.1, L25.2 (DOUT), L26.4 (DIN)
unnamed: JP10.2, L23.2 (DOUT), L24.4 (DIN)
unnamed: JP11.1, L34.2 (DOUT), L35.4 (DIN)
unnamed: JP11.2, L32.2 (DOUT), L33.4 (DIN)
unnamed: L7.2 (DOUT), L8.4 (DIN)
unnamed: L8.2 (DOUT), L9.4 (DIN)
unnamed: L10.2 (DOUT), L11.4 (DIN)
unnamed: L9.2 (DOUT), L10.4 (DIN)
unnamed: L11.2 (DOUT), L12.4 (DIN)
unnamed: L12.2 (DOUT), L13.4 (DIN)
unnamed: L14.2 (DOUT), L15.4 (DIN)
unnamed: L17.2 (DOUT), L18.4 (DIN)
unnamed: L18.2 (DOUT), L19.4 (DIN)
unnamed: L19.2 (DOUT), L20.4 (DIN)
unnamed: L20.2 (DOUT), L21.4 (DIN)
unnamed: L21.2 (DOUT), L22.4 (DIN)
unnamed: L22.2 (DOUT), L23.4 (DIN)
unnamed: L24.2 (DOUT), L25.4 (DIN)
unnamed: L27.2 (DOUT), L28.4 (DIN)
unnamed: L28.2 (DOUT), L29.4 (DIN)
unnamed: L29.2 (DOUT), L30.4 (DIN)
unnamed: L30.2 (DOUT), L31.4 (DIN)
unnamed: L31.2 (DOUT), L32.4 (DIN)
unnamed: L33.2 (DOUT), L34.4 (DIN)
unnamed: L35.2 (DOUT), L36.4 (DIN)
unnamed: L36.2 (DOUT), L37.4 (DIN)
unnamed: L37.2 (DOUT), L38.4 (DIN)
unnamed: P3.1, SW33.1 (A)
unnamed: SW33.2 (B), U1.24 (RAW)
PIN21: J1.1, JP12.1, R1.2, R2.1, SW34.2 (B), U1.21 (VCC)
RST: SW0.1, U1.22 (RST)
SCL: JP3.2, JP6.2, R1.1, U1.6 (SCL(PD0))
SDA: JP4.2, JP5.2, R2.2, U1.5 (SDA(PD1))
VCC: JP2.2, JP7.2, JP12.2, L7.1 (VDD), L8.1 (VDD), L9.1 (VDD), L10.1 (VDD), L11.1 (VDD), L12.1 (VDD), L13.1 (VDD), L14.1 (VDD), L15.1 (VDD), L16.1 (VDD), L17.1 (VDD), L18.1 (VDD), L19.1 (VDD), L20.1 (VDD), L21.1 (VDD), L22.1 (VDD), L23.1 (VDD), L24.1 (VDD), L25.1 (VDD), L26.1 (VDD), L27.1 (VDD), L28.1 (VDD), L29.1 (VDD), L30.1 (VDD), L31.1 (VDD), L32.1 (VDD), L33.1 (VDD), L34.1 (VDD), L35.1 (VDD), L36.1 (VDD), L37.1 (VDD), L38.1 (VDD), SW34.1 (A)
col0: SW1.2, SW7.2, SW13.2, SW20.2, SW27.2, U1.19 (A2(PF5))
col1: SW2.2, SW8.2, SW14.2, SW21.2, U1.18 (A1(PF6))
col2: ENC3.S2, SW3.2, SW9.2, SW15.2, SW22.2, SW28.2, U1.17 (A0(PF7))
col3: SW4.2, SW10.2, SW16.2, SW23.2, SW29.2, U1.16 (D15(PB1))
col4: SW5.2, SW11.2, SW17.2, SW24.2, SW30.2, U1.15 (D14(PB3))
col5: SW6.2, SW12.2, SW18.2, SW25.2, SW31.2, U1.14 (D16(PB2))
col6: ENC1.S2, ENC2.S2, SW19.2, SW26.2, SW32.2, U1.13 (D10(PB6))
encA: ENC1.A, ENC2.A, ENC3.A, U1.12 (D9(PB5))
encB: ENC1.B, ENC2.B, ENC3.B, U1.20 (A3(PF4))
ledB: L16.2 (DOUT), L17.4 (DIN)
ledC: L26.2 (DOUT), L27.4 (DIN)
row0: D1.1 (K), D2.1 (K), D3.1 (K), D4.1 (K), D5.1 (K), D6.1 (K), U1.7 (D4(PD4))
row1: D7.1 (K), D8.1 (K), D9.1 (K), D10.1 (K), D11.1 (K), D12.1 (K), U1.8 (D5(PC6))
row2: D13.1 (K), D14.1 (K), D15.1 (K), D16.1 (K), D17.1 (K), D18.1 (K), D19.1 (K), U1.9 (D6(PD7))
row3: D20.1 (K), D21.1 (K), D22.1 (K), D23.1 (K), D24.1 (K), D25.1 (K), D26.1 (K), U1.10 (D7(PE6))
row4: D27.1 (K), D28.1 (K), D29.1 (K), D30.1 (K), D31.1 (K), D32.1 (K), U1.11 (D8(PB4))
sw19r: D19.2 (A), ENC1.S1, SW19.1
sw26r: D26.2 (A), ENC2.S1, SW26.1
sw28r: D28.2 (A), ENC3.S1, SW28.1

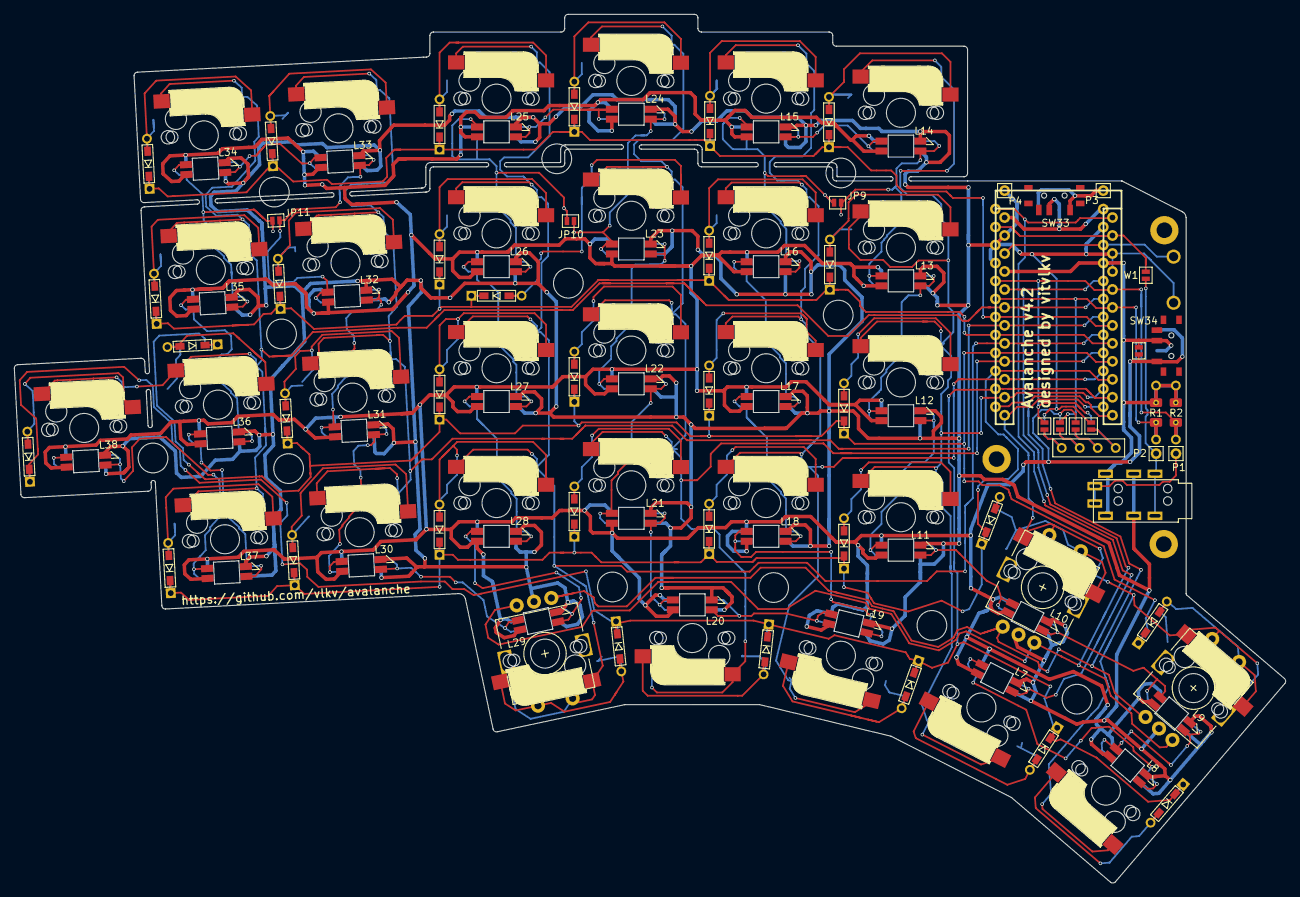
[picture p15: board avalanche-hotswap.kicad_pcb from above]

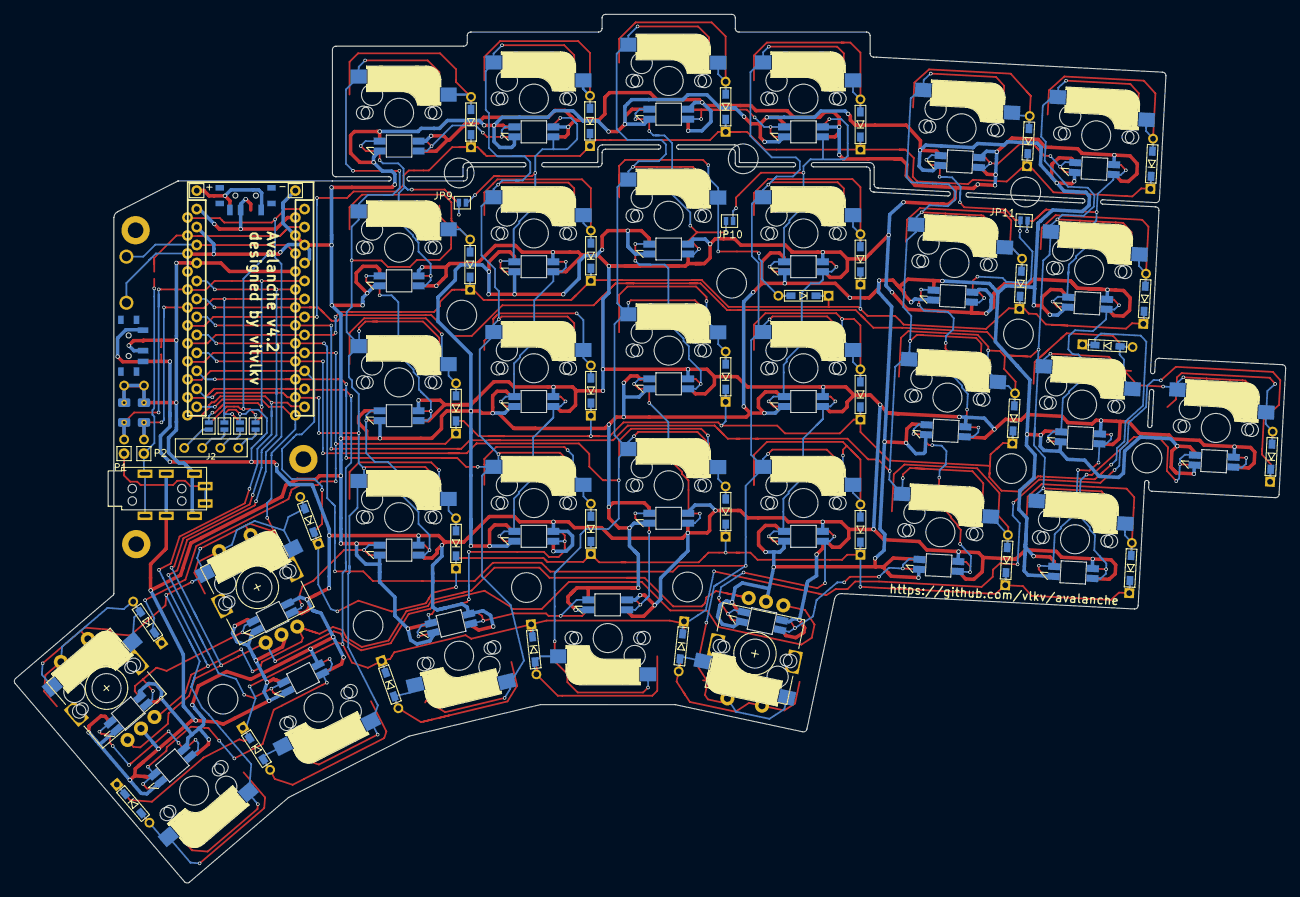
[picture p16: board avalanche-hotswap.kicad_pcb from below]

Board: 2 copper layers, 179.7 x 122.7 mm, 139 parts (5 on the bottom side), 93 nets.

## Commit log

2021-02-25 Initial commit with my current pcb project "Thing60"
    [emu-hotswap.kicad_pcb, emu-hotswap.sch]
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2021-02-26 Lined everything up to grid 0.05mm
    [emu-hotswap.kicad_pcb]
2021-02-26 Positioned rows and cols
    [emu-hotswap.kicad_pcb]
2021-02-26 Roughly cut edges, fixed footprints on the scheme.
    [emu-hotswap.kicad_pcb, emu-hotswap.sch]
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2021-02-27 Rotated thumb switches to 180 degrees.
    [emu-hotswap.kicad_pcb, emu-hotswap.sch]
2021-02-27 All routes seems to be connected.
    [emu-hotswap.kicad_pcb]
2021-02-28 Moved diode a bit
    [emu-hotswap.kicad_pcb]
2021-02-28 Aligned everything to 0.05 grid.
    [emu-hotswap.kicad_pcb]
2021-02-28 Aligned cut to 0.05 grid.
    [emu-hotswap.kicad_pcb]
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2021-02-28 Routing dual ProMicro footprint
    [emu-hotswap.kicad_pcb, emu-hotswap.sch]
2021-02-28 Routing dual ProMicro footprint. Done.
    [emu-hotswap.kicad_pcb]
2021-02-28 Fixed ProMicro footprint silk layer
    [emu-hotswap.kicad_pcb]
2021-02-28 Updated fotprint on the scheme
    [emu-hotswap.kicad_pcb]
2021-03-02 Started new simple and weird design.
    [emu-hotswap.kicad_pcb, emu-hotswap.sch]
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2021-03-04 Renamed emu to avalanche
    [avalanche-hotswap.kicad_pcb, avalanche-hotswap.sch]
2021-03-04 Added text to the PCB
    [avalanche-hotswap.kicad_pcb]
2021-03-05 Added to schema: * OLED * LED
    Imported some footprints and symbols from Lily58
    [avalanche-hotswap.sch]
2021-03-05 Moved all symbols to avalanche-hotswap.lib
    [avalanche-hotswap.sch]
2021-03-05 Added underglow LEDs and many more...
    [avalanche-hotswap.kicad_pcb, avalanche-hotswap.sch, plate_bottom.kicad_pcb]
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2021-03-07 Renumbered switches and diodes.
    [avalanche-hotswap.kicad_pcb, avalanche-hotswap.sch]
2021-03-07 Added one more underglow LED
    [avalanche-hotswap.kicad_pcb, avalanche-hotswap.sch]
2021-03-08 Prepared to route the promicro
    [avalanche-hotswap.kicad_pcb]
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2021-03-08 Added GND filled zones.
    [avalanche-hotswap.kicad_pcb]
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2021-03-08 Fixed cut edges + filled zones on plates.
    [avalanche-hotswap.kicad_pcb, plate_bottom.kicad_pcb, plate_top.kicad_pcb]
2021-03-08 Using different cutout footprints
    [plate_top.kicad_pcb]
2021-03-08 Using different M2 holes.
    [avalanche-hotswap.kicad_pcb, avalanche-hotswap.sch]
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2021-03-08 Minor improvements for holes.
    [avalanche-hotswap.kicad_pcb]
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2021-03-08 Reduced width of the top plate for 0.05mm
    [plate_top.kicad_pcb]
2021-03-08 Regenerated Gerbers for top plate
    [plate_top.kicad_pcb]
2021-03-08 Changed layer from silk to comments
    [plate_top.kicad_pcb]
2021-03-08 Added User Drawings layer to gerbers
    [plate_top.kicad_pcb]
2021-04-06 Created project for cover plate
    [cover.kicad_pcb, cover.sch]
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2021-04-07 Printed layout tester to PDF
    [layout_tester.kicad_pcb]
2021-04-07 - Moved SW13 to a different row and col (needed to free one ProMicro pin) - Added rotary encoders to the scheme - Added rotary encoders footprint
    [avalanche-hotswap.sch]
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2021-04-07 - Added encoders to their place. Not routed yet. - Moved one case hole. Both on pcb and bottom-plate.
    [avalanche-hotswap.kicad_pcb, plate_bottom.kicad_pcb]
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2021-04-08 Routed all three encoders
    [avalanche-hotswap.kicad_pcb]
2021-04-08 Moved case hole more downwards
    [avalanche-hotswap.kicad_pcb, plate_bottom.kicad_pcb]
2021-04-08 moved reset button a bit down
    [avalanche-hotswap.kicad_pcb]
2021-04-08 Changed LEDs to WS2812B
    [avalanche-hotswap.kicad_pcb, avalanche-hotswap.sch]
2021-04-08 Updated version label. Moved OLED connections a bit down.
    [avalanche-hotswap.kicad_pcb]
2021-04-10 Started replacing diodes footprints (SMD only).
    [avalanche-hotswap.kicad_pcb, avalanche-hotswap.sch]
2021-04-10 WIP on smd diodes...
    [avalanche-hotswap.kicad_pcb, avalanche-hotswap.sch]
2021-04-10 WIP on diodes. Moved a case hole a little bit
    [avalanche-hotswap.kicad_pcb, avalanche-hotswap.sch, plate_bottom.kicad_pcb]
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2021-04-10 WIP on diodes. Almost done.
    [avalanche-hotswap.kicad_pcb, avalanche-hotswap.sch]
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2021-04-11 Routing encoder after rotate. Moved case hole a little.
    [avalanche-hotswap.kicad_pcb, plate_bottom.kicad_pcb]
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2021-04-13 Added jumpers for LEDs in case of nums row break-off
    [avalanche-hotswap.kicad_pcb, avalanche-hotswap.sch]
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2021-04-15 Fixed ground routing
    [avalanche-hotswap.kicad_pcb]
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2021-04-15 Swapped LED 36 and 37 to fix break-offability of the pinky key.
    [avalanche-hotswap.kicad_pcb]
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2021-04-17 Moved diodes a little bit away from rotary encoders
    [avalanche-hotswap.kicad_pcb]
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2021-04-17 Fixed problem with a monting hole. Moved P1 and P2 up (closer to the resistors)
    [avalanche-hotswap.kicad_pcb]
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2021-04-18 Minor fix of the via
    [avalanche-hotswap.kicad_pcb]
2021-04-18 Replaced diode footprints with smd+th
    [avalanche-hotswap.kicad_pcb, avalanche-hotswap.sch, plate_bottom.kicad_pcb]
2021-04-18 Minor fixes in diodes
    [avalanche-hotswap.kicad_pcb]
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2021-04-22 Fixed LED footprints
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2021-04-22 Fixed LED symbol
2021-04-22 Fixed scheme and netlist
    [avalanche-hotswap.sch]
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2021-04-22 Minor fix
    [avalanche-hotswap.kicad_pcb]
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2021-04-24 Moving thumb cluster to the right a bit... WIP
    [avalanche-hotswap.kicad_pcb]
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2021-04-25 Working on a new design for the top plate.
    [avalanche-hotswap.kicad_pcb, plate_top.kicad_pcb]
2021-04-25 Routed RESET in its new location.
    [avalanche-hotswap.kicad_pcb, avalanche-hotswap.sch]
2021-04-25 Multiple fixes...
    [avalanche-hotswap.kicad_pcb, cover.kicad_pcb, plate_bottom.kicad_pcb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]
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2021-04-30 Cleaned up tracks and vias + minor change.
    [avalanche-hotswap.kicad_pcb]
2021-04-30 Corrected a label
    [avalanche-hotswap.kicad_pcb]
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2021-04-30 Removed copper layers from top and bottom plates
    [plate_bottom.kicad_pcb, plate_top.kicad_pcb]
2021-06-08 Rotated R1. Updated the label with version on silk layer
    [avalanche-hotswap.kicad_pcb]
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2021-07-03 Reverted the sch and netlist (Returned back SW19)
    [avalanche-hotswap.sch]
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2021-07-05 Fixed location of two buttons in thumb cluster
    [avalanche-hotswap.kicad_pcb]
2021-07-05 Multiple fixes
    [avalanche-hotswap.kicad_pcb, plate_bottom.kicad_pcb, plate_top.kicad_pcb]
2021-07-05 Added reset label
    [avalanche-hotswap.kicad_pcb]
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2021-07-26 Fixed the footprint #8
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2021-08-01 Fixed #9 (Problems after breaking-off the numbers row)
    [avalanche-hotswap.kicad_pcb]
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2021-09-03 Fixed standoffs in the parts list
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2021-09-03 Updated all the LED footprints on the pcb
    [avalanche-hotswap.kicad_pcb]
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2021-10-16 Reduced the angle of "pinky stagger" for 1.5 degrees
    [avalanche-hotswap.kicad_pcb]
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2021-10-19 Fixed edges
    [avalanche-hotswap.kicad_pcb]
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2021-10-21 Routing is fixed
    [avalanche-hotswap.kicad_pcb]
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2021-10-22 Final fixes for v4.1
    [avalanche-hotswap.kicad_pcb, plate_top.kicad_pcb]
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2021-12-10 Fixed GND shortened to RST in Avalanche 4.0 and 4.1 #10
    [avalanche-hotswap.kicad_pcb]
2021-12-10 Change the OLED pins order in Avalanche 4.0 and 4.1 #11
    [avalanche-hotswap.kicad_pcb, avalanche-hotswap.sch]
2021-12-10 Changed the version to 4.2 on the silkscreen
    [avalanche-hotswap.kicad_pcb]
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
